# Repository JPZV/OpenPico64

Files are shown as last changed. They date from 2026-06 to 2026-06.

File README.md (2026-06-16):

# OpenPico64
Nintendo 64 flash cart using a Raspberry Pi Pico / RP2040 based on [kbeckmann](https://twitter.com/kbeckmann) [PicoCart64](https://github.com/kbeckmann/PicoCart64)

## How to build an OpenPico64

### Getting the raw PCB

- Download the `openpico64.gerber.zip` file from [Releases](https://github.com/JPZV/OpenPico64/releases/latest).

- Go to a PCB manufacturing service such as [JLCPCB](https://jlcpcb.com), [OSH Park](https://oshpark.com/), [PCBWay](https://pcbway.com) or similar.

- This takes you to the PCB configuration utility where you can upload the `.zip` from above. After uploading, you should see a rendered version of both sides of the PCB. If you want to produce a cheap cart for testing you can leave all settings as they are, except for this one:

  - ⚠️ *PCB Thickness* needs to be set to *1.2mm*, otherwise the cart won't fit in your console

⚠️ Note that this will result in a PCB with 90 degrees edges - the edge connector should be sanded down to get a nice 45 degree V shape. If this is not done, it may wear down your cart connector on the N64. The proper PCB order should be ENIG-RoHS + Gold Fingers + 45°finger chamfered, however this will result in a significant cost increase.

### Sourcing the components

In order to ensambe it you will need the following parts along with the PCBs. Here we're assuming you want to assemble 5 boards, as that is the number of PCBs you'll be getting from many PCB manufacturing services as a minimum.

⚠️ Note that this project **IS NOT** compatible with the original/oem `Raspberry Pi Pico`. **YOU HAVE** to use the [WeAct clone](https://aliexpress.com/item/1005003708090298.html) because it has more exposed pins which we need. I repeat, **DON'T** use the Raspberry Branded board (the green one with a Raspberry at the bottom), it will likely fry your N64 at best. I do recommend you to buy the 8MB version or higher, as I don't know how much will grow this project.

| Qty | Name | Source | 
|-----|---|---|
| 5 | WeAct Raspberry Pi Pico | [AliExpress](https://aliexpress.com/item/1005003708090298.html) | |
| 5 | BSS84 MOSFET | [750-BSS84-HF](https://www.mouser.com/ProductDetail/750-BSS84-HF) | |
| 5 | 0603 100k resistor | [71-CRCW0603100KJNEAC](https://www.mouser.com/ProductDetail/71-CRCW0603100KJNEAC) | |
| 5 | ATTINY85-20PU | [556-ATTINY85-20PU](https://www.mouser.com/ProductDetail/556-ATTINY85-20PU) | |

### Preparing the CIC (ATTiny85)

You have to flash the ATTiny85 with [UltraCIC](https://github.com/ManCloud/UltraCIC-III) before assembling everything else. You can do it with the OpenPico64 board headers to an easy installation. Then, **remember** to join the JP2 jumper!  

### Assembling the board

If your WeAct Pico didn't come with the headers ready, you'll have to solder them beforehand. Then, put the Pico on the OpenPico64 board with the USB connector facing outwards and solder the headers.

Solder the MOSFET according to the pin markings.

The resistor is optional to solder, but was placed there for good measure. (There is a resistor on the Pico, so it is not strictly needed.)

### Flashing/Updating the firmware

Go to the [Releases](https://github.com/JPZV/OpenPico64/releases/latest) and download the latest .UF2 file. **Remove the OpenPico64 from your N64**, then press and hold the **BOOTSEL** button while connecting the Pico to your computer. Open your file explorer (Explorer on Windows, Fiddle on Mac, and file manager in Linux), navigate to the new Flash memory, copy and paste the .UF2, and wait until it closes.

⚠️ **DON'T** use your OpenPico64 in your N64 while it's connected to your PC or anything. The N64 works with 3.3V and your computer with 5V, so likely it'll fry your N64.

## License

The PCB is licensed under the following license: "CERN Open Hardware Licence Version 2 - Permissive" aka "CERN-OHL-P".

The software is licensed under BSD-2-Clause unless otherwise specified.

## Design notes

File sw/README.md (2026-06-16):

To build and flash with a j-link:

```bash

# First of all, don't forget to update submodules
git submodule update --init

# If you have more than 2MB flash, you need to change the SDK file src/rp2_common/pico_standard_link/memmap_copy_to_ram.ld (for now!):
# Change to: `FLASH(rx) : ORIGIN = 0x10000000, LENGTH = 16384k`

cd sw

# Load a rom into sw/picocart64/rom.h
# `--compress` will compress the rom with a simple compression scheme.
./scripts/load_rom.py --compress my_rom.z64

mkdir build
cd build

# Configure cmake. To use NTSC, set -DREGION=NTSC
# If you have more than 2MB flash, you need to change the flash size by adding -DFLASH_SIZE_MB={one of 2,4,8,16} here.

cmake -DREGION=PAL ..

# Build
cmake --build .

# You can now flash it by holding down the BOOT button and resetting the device, then mounting the usb mass storage device, then copy the file openpico64/openpico64.uf2 to the mounted path and run `sync`.

# Alternatively, you can use openocd with a J-Link:

# Requires https://github.com/raspberrypi/openocd
# AUR package if you're on archlinux: https://aur.archlinux.org/packages/openocd-raspberrypi-git
openocd -f interface/jlink.cfg -c "transport select swd; adapter_khz 1000" -f target/rp2040.cfg -c "program ./openpico64/openpico64.elf verify reset exit"

# Note! You *have* to power reset the pico after flashing it with a jlink, otherwise multicore doesn't work properly.
# Alternatively, attach a debugger, `mon reset halt`, `c`, does the trick as well. It seems that openocd's `reset run` doesn't work properly.

```

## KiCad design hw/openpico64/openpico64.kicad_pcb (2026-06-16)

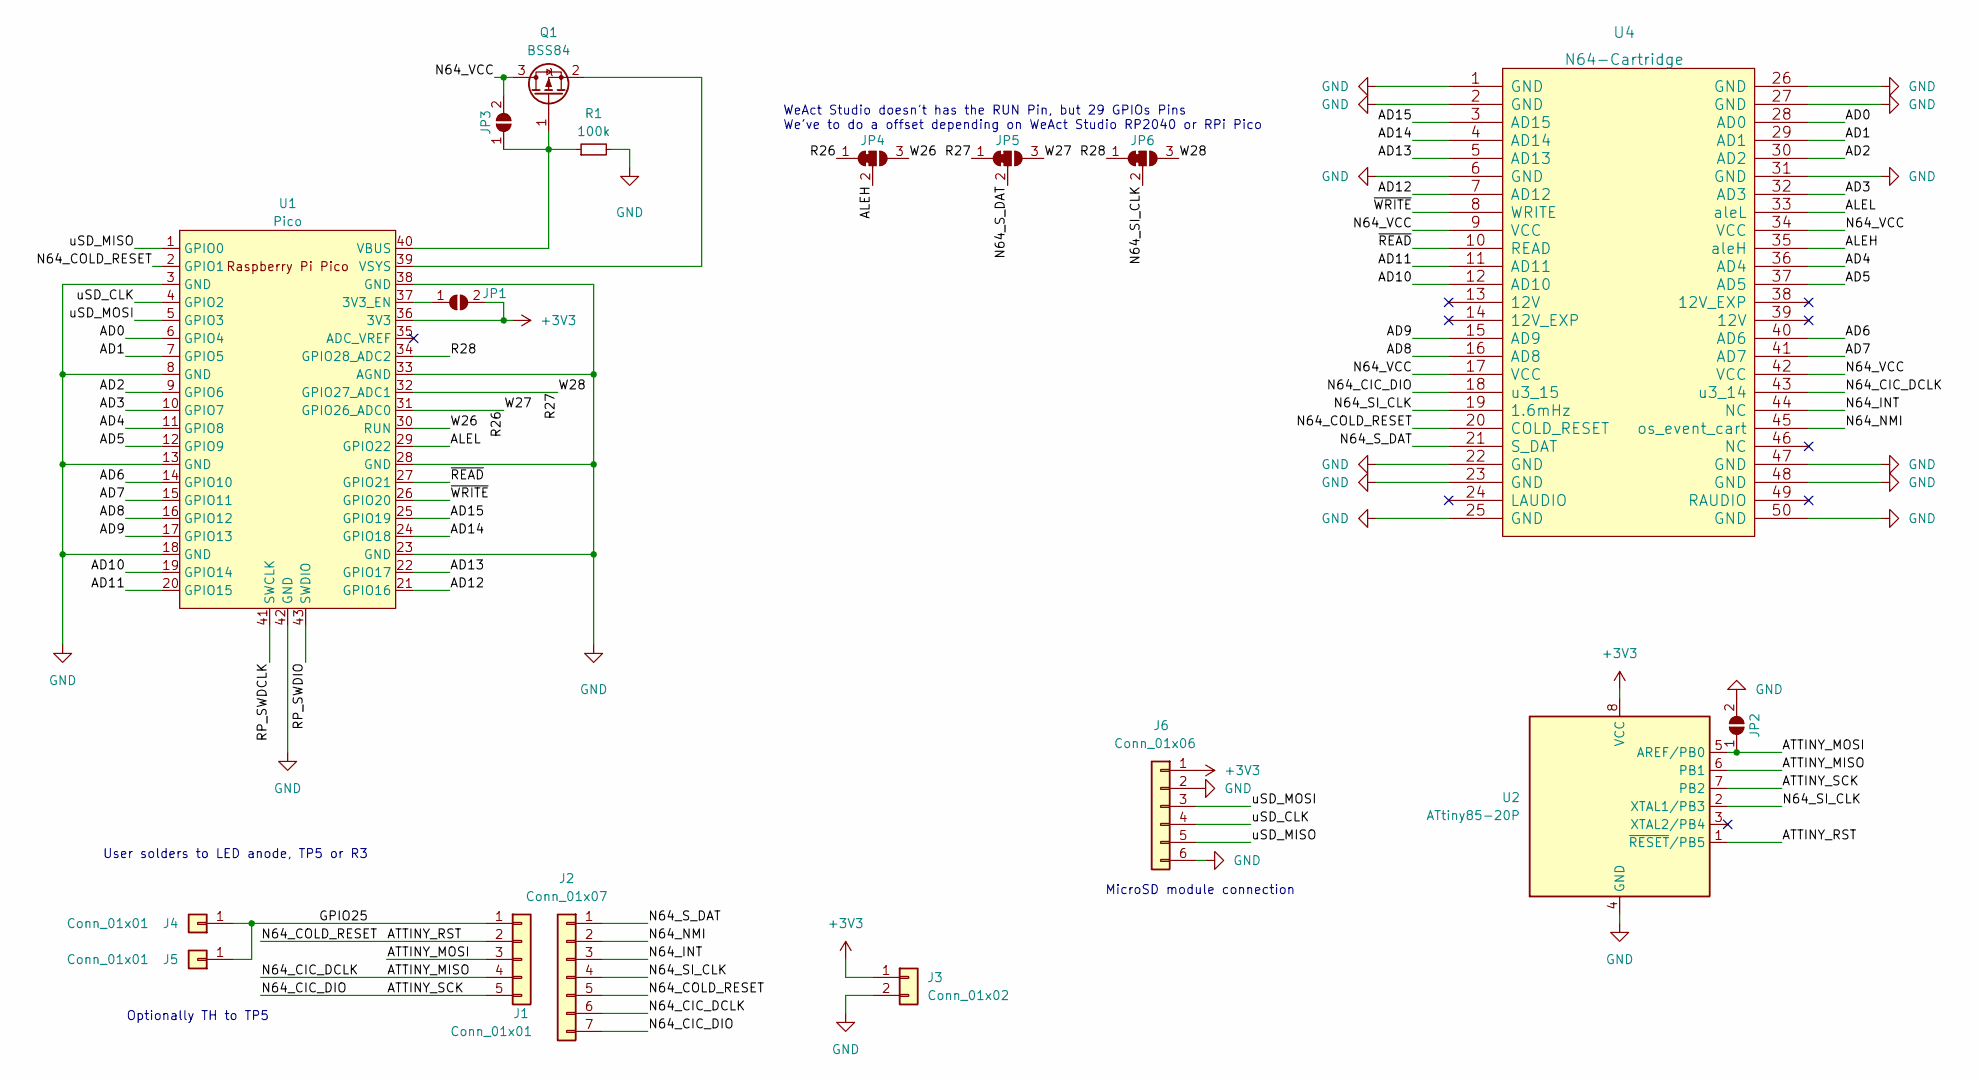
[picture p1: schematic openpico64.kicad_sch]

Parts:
J1: Conn_01x01; PinHeader_1x05_P2.54mm_Vertical
J2: Conn_01x07; PinHeader_1x07_P2.54mm_Vertical
J3: Conn_01x02; PinHeader_1x08_P2.54mm_Vertical
J4, J5: Conn_01x01; PinHeader_1x01_P2.54mm_Vertical
J6: Conn_01x06; PinHeader_1x06_P2.54mm_Vertical
JP1, JP2, JP3: SolderJumper_2_Open; SolderJumper-2_P1.3mm_Open_RoundedPad1.0x1.5mm
JP4, JP5, JP6: SolderJumper_3_Bridged12; SolderJumper-3_P1.3mm_Bridged12_RoundedPad1.0x1.5mm_NumberL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
Q1: BSS84; SOT-23
R1: 100k; R_0603_1608Metric_Pad0.98x0.95mm_HandSolder
U1: Pico; RPi_Pico_SMD_TH
U2: ATtiny85-20P; DIP-8_W7.62mm
U4: N64-Cartridge; N64-Connector

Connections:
+3V3: J3.1, J6.1, JP1.2 (B), U1.36 (3V3), U2.8 (VCC)
/AD0: U1.6 (GPIO4), U4.28 (AD0)
/AD1: U1.7 (GPIO5), U4.29 (AD1)
/AD2: U1.9 (GPIO6), U4.30 (AD2)
/AD3: U1.10 (GPIO7), U4.32 (AD3)
/AD4: U1.11 (GPIO8), U4.36 (AD4)
/AD5: U1.12 (GPIO9), U4.37 (AD5)
/AD6: U1.14 (GPIO10), U4.40 (AD6)
/AD7: U1.15 (GPIO11), U4.41 (AD7)
/AD8: U1.16 (GPIO12), U4.16 (AD8)
/AD9: U1.17 (GPIO13), U4.15 (AD9)
/AD10: U1.19 (GPIO14), U4.12 (AD10)
/AD11: U1.20 (GPIO15), U4.11 (AD11)
/AD12: U1.21 (GPIO16), U4.7 (AD12)
/AD13: U1.22 (GPIO17), U4.5 (AD13)
/AD14: U1.24 (GPIO18), U4.4 (AD14)
/AD15: U1.25 (GPIO19), U4.3 (AD15)
/ALEH: JP4.2 (C), U4.35 (aleH)
/ALEL: U1.29 (GPIO22), U4.33 (aleL)
/ATTINY_MISO: J1.4, J2.6, U2.6 (PB1), U4.43 (u3_14)
/ATTINY_MOSI: J1.3, JP2.1 (A), U2.5 (AREF/PB0)
/ATTINY_RST: J1.2, J2.5, U1.2 (GPIO1), U2.1 (~RESET/PB5), U4.20 (COLD_RESET)
/ATTINY_SCK: J1.5, J2.7, U2.7 (PB2), U4.18 (u3_15)
/GPIO25: J1.1, J4.1, J5.1
/N64_INT: J2.3, U4.44 (NC)
/N64_NMI: J2.2, U4.45 (os_event_cart)
/N64_SI_CLK: J2.4, JP6.2 (C), U2.2 (XTAL1/PB3), U4.19 (1.6mHz)
/N64_S_DAT: J2.1, JP5.2 (C), U4.21 (S_DAT)
/N64_VCC: JP3.2 (B), Q1.3 (D), U4.9 (VCC), U4.17 (VCC), U4.34 (VCC), U4.42 (VCC)
/R26: JP4.1 (A), JP5.3 (B), U1.31 (GPIO26_ADC0)
/R27: JP5.1 (A), JP6.3 (B), U1.32 (GPIO27_ADC1)
/R28: JP6.1 (A), U1.34 (GPIO28_ADC2)
/RP_SWDCLK: U1.41 (SWCLK)
/RP_SWDIO: U1.43 (SWDIO)
/W26: JP4.3 (B), U1.30 (RUN)
/uSD_CLK: J6.4, U1.4 (GPIO2)
/uSD_MISO: J6.5, U1.1 (GPIO0)
/uSD_MOSI: J6.3, U1.5 (GPIO3)
/~READ: U1.27 (GPIO21), U4.10 (READ)
/~WRITE: U1.26 (GPIO20), U4.8 (WRITE)
GND: J3.2, J6.2, J6.6, JP2.2 (B), R1.2, U1.3 (GND), U1.8 (GND), U1.13 (GND), U1.18 (GND), U1.23 (GND), U1.28 (GND), U1.33 (AGND), U1.38 (GND), U1.42 (GND), U2.4 (GND), U4.1 (GND), U4.2 (GND), U4.6 (GND), U4.22 (GND), U4.23 (GND), U4.25 (GND), U4.26 (GND), U4.27 (GND), U4.31 (GND), U4.47 (GND), U4.48 (GND), U4.50 (GND)
unnamed: JP1.1 (A), U1.37 (3V3_EN)
unnamed: JP3.1 (A), Q1.1 (G), R1.1, U1.40 (VBUS)
unnamed: Q1.2 (S), U1.39 (VSYS)

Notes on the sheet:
WeAct Studio doesn't has the RUN Pin, but 29 GPIOs Pins We've to do a offset depending on WeAct Studio RP2040 or RPi Pico
User solders to LED anode, TP5 or R3
Optionally TH to TP5
MicroSD module connection

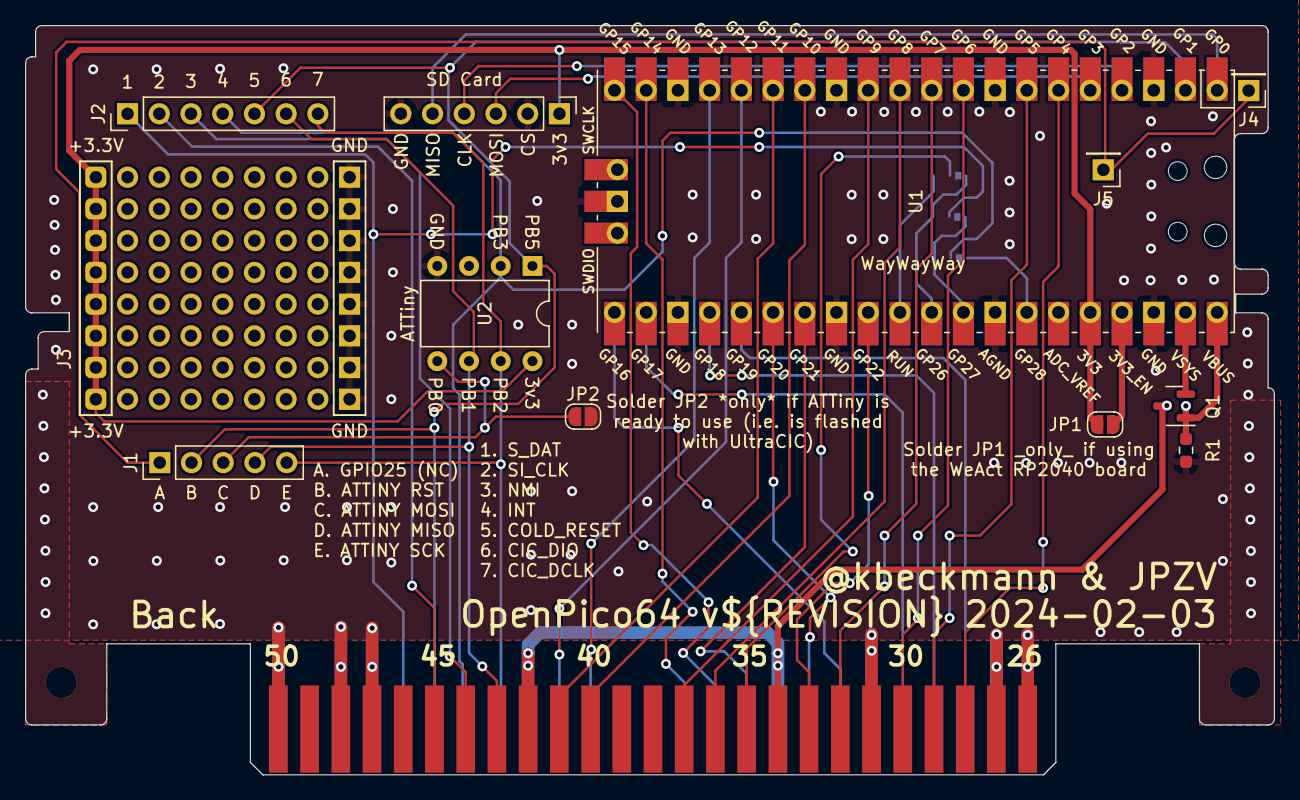
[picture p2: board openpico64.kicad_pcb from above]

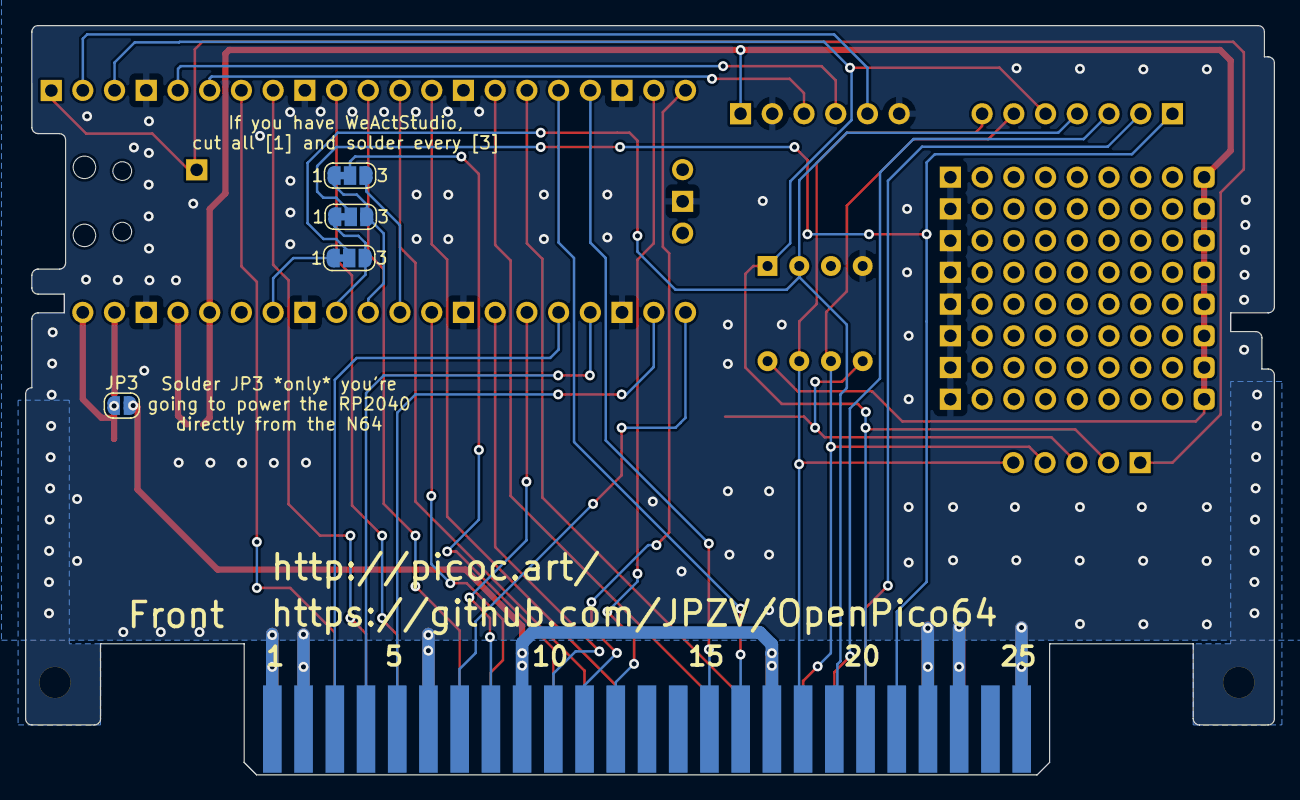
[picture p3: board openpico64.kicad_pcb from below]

Board: 2 copper layers, 100.0 x 60.0 mm, 17 parts (5 on the bottom side), 42 nets.

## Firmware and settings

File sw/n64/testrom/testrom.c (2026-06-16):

/**
 * SPDX-License-Identifier: BSD-2-Clause
 *
 * Copyright (c) 2022 Konrad Beckmann <konrad.beckmann@gmail.com>
 * Copyright (c) 2022 Christopher Bonhage <me@christopherbonhage.com>
 * Copyright (c) 2026 JPZV
 *
 * Based on https://github.com/meeq/SaveTest-N64
 */

#include <string.h>
#include <libdragon.h>

#include "git_info.h"
#include "shell.h"
#include "testrom.h"

// picocart64_shared
#include "pc64_regs.h"
#include "pc64_rand.h"
#include "n64_defs.h"

typedef struct PI_regs_s {
	volatile void *ram_address;
	uint32_t pi_address;
	uint32_t read_length;
	uint32_t write_length;
} PI_regs_t;
static volatile PI_regs_t *const PI_regs = (PI_regs_t *) 0xA4600000;

// SD Card Test constants
#define SD_TEST_PATH				"/New Path/My Folder/"

static void verify_memory_range(uint32_t base, uint32_t offset, uint32_t len)
{
	uint32_t start = base + offset;
	uint32_t end = start + len - 1;

	switch (base) {
	case CART_DOM2_ADDR1_START:
		assert(start >= CART_DOM2_ADDR1_START);
		assert(start <= CART_DOM2_ADDR1_END);
		assert(end >= CART_DOM2_ADDR1_START);
		assert(end <= CART_DOM2_ADDR1_END);
		break;

	case CART_DOM1_ADDR1_START:
		assert(start >= CART_DOM1_ADDR1_START);
		assert(start <= CART_DOM1_ADDR1_END);
		assert(end >= CART_DOM1_ADDR1_START);
		assert(end <= CART_DOM1_ADDR1_END);
		break;

	case CART_DOM2_ADDR2_START:
		assert(start >= CART_DOM2_ADDR2_START);
		assert(start <= CART_DOM2_ADDR2_END);
		assert(end >= CART_DOM2_ADDR2_START);
		assert(end <= CART_DOM2_ADDR2_END);
		break;

	case CART_DOM1_ADDR2_START:
		assert(start >= CART_DOM1_ADDR2_START);
		assert(start <= CART_DOM1_ADDR2_END);
		assert(end >= CART_DOM1_ADDR2_START);
		assert(end <= CART_DOM1_ADDR2_END);
		break;

	case CART_DOM1_ADDR3_START:
		assert(start >= CART_DOM1_ADDR3_START);
		assert(start <= CART_DOM1_ADDR3_END);
		assert(end >= CART_DOM1_ADDR3_START);
		assert(end <= CART_DOM1_ADDR3_END);
		break;

	case PC64_BASE_ADDRESS_START:
		assert(start >= PC64_BASE_ADDRESS_START);
		assert(start <= PC64_BASE_ADDRESS_END);
		assert(end >= PC64_BASE_ADDRESS_START);
		assert(end <= PC64_BASE_ADDRESS_END);
		break;

	case PC64_RAND_ADDRESS_START:
		assert(start >= PC64_RAND_ADDRESS_START);
		assert(start <= PC64_RAND_ADDRESS_END);
		assert(end >= PC64_RAND_ADDRESS_START);
		assert(end <= PC64_RAND_ADDRESS_END);
		break;

	case PC64_CIBASE_ADDRESS_START:
		assert(start >= PC64_CIBASE_ADDRESS_START);
		assert(start <= PC64_CIBASE_ADDRESS_END);
		assert(end >= PC64_CIBASE_ADDRESS_START);
		assert(end <= PC64_CIBASE_ADDRESS_END);
		break;
	
	case SD_PATH_ADDR_START:
	case SD_GAME_PATH_ADDR_START:
	case SD_STATUS_ADDR_START:
	case SD_DIR_LIST_LEN_ADDR_START:
	case SD_DIR_LIST_ADDR_START:
		assert(start >= SD_ADDR_START);
		assert(start <= SD_ADDR_END);
		assert(end >= SD_ADDR_START);
		assert(end <= SD_ADDR_END);
		break;

	default:
		assert(!"Unsupported base");
	}
}

void pi_read_raw(void *dest, uint32_t base, uint32_t offset, uint32_t len)
{
	assert(dest != NULL);
	verify_memory_range(base, offset, len);

	disable_interrupts();
	dma_wait();

	MEMORY_BARRIER();
	PI_regs->ram_address = UncachedAddr(dest);
	MEMORY_BARRIER();
	PI_regs->pi_address = offset + base;
	MEMORY_BARRIER();
	PI_regs->write_length = len - 1;
	MEMORY_BARRIER();

	enable_interrupts();
	dma_wait();
}

void pi_write_raw(const void *src, uint32_t base, uint32_t offset, uint32_t len)
{
	assert(src != NULL);
	verify_memory_range(base, offset, len);

	disable_interrupts();
	dma_wait();

	MEMORY_BARRIER();
	PI_regs->ram_address = UncachedAddr(src);
	MEMORY_BARRIER();
	PI_regs->pi_address = offset + base;
	MEMORY_BARRIER();
	PI_regs->read_length = len - 1;
	MEMORY_BARRIER();

	enable_interrupts();
	dma_wait();
}

static void pi_write_u32(const uint32_t value, uint32_t base, uint32_t offset)
{
	uint32_t buf[] = { value };

	data_cache_hit_writeback_invalidate(buf, sizeof(buf));
	pi_write_raw(buf, base, offset, sizeof(buf));
}

static uint8_t __attribute__((aligned(16))) facit_buf[SRAM_1MBIT_SIZE];
static uint8_t __attribute__((aligned(16))) read_buf[SRAM_1MBIT_SIZE];
static char __attribute__((aligned(16))) write_buf[0x1000];

char __attribute__((aligned(16))) path_read_buf[SD_PATH_LENGTH];

static void pc64_uart_write(const uint8_t * buf, uint32_t len)
{
	// 16-bit aligned
	assert((((uint32_t) buf) & 0x1) == 0);

	uint32_t len_aligned32 = (len + 3) & (-4);

	data_cache_hit_writeback_invalidate((uint8_t *) buf, len_aligned32);
	pi_write_raw(write_buf, PC64_BASE_ADDRESS_START, 0, len_aligned32);

	pi_write_u32(len, PC64_CIBASE_ADDRESS_START, PC64_REGISTER_UART_TX);
}

static void configure_sram(void)
{
	// PI registers
#define PI_BASE_REG          0x04600000
#define PI_STATUS_REG        (PI_BASE_REG+0x10)
#define	PI_STATUS_ERROR      0x04
#define PI_STATUS_IO_BUSY    0x02
#define PI_STATUS_DMA_BUSY   0x01

#define PI_BSD_DOM1_LAT_REG  (PI_BASE_REG+0x14)
#define PI_BSD_DOM1_PWD_REG  (PI_BASE_REG+0x18)
#define PI_BSD_DOM1_PGS_REG  (PI_BASE_REG+0x1C)
#define PI_BSD_DOM1_RLS_REG  (PI_BASE_REG+0x20)
#define PI_BSD_DOM2_LAT_REG  (PI_BASE_REG+0x24)
#define PI_BSD_DOM2_PWD_REG  (PI_BASE_REG+0x28)
#define PI_BSD_DOM2_PGS_REG  (PI_BASE_REG+0x2C)
#define PI_BSD_DOM2_RLS_REG  (PI_BASE_REG+0x30)

	// MIPS addresses
#define KSEG0 0x80000000
#define KSEG1 0xA0000000

	// Memory translation stuff
#define	PHYS_TO_K1(x)       ((uint32_t)(x)|KSEG1)
#define	IO_WRITE(addr,data) (*(volatile uint32_t *)PHYS_TO_K1(addr)=(uint32_t)(data))
#define	IO_READ(addr)       (*(volatile uint32_t *)PHYS_TO_K1(addr))

	// Initialize the PI
	IO_WRITE(PI_STATUS_REG, 3);

	// SDK default, 0x80371240
	//                  DCBBAA
	// AA = LAT
	// BB = PWD
	//  C = PGS
	//  D = RLS
	//
	// 1 cycle = 1/62.5 MHz = 16ns
	// Time = (register+1)*16ns
	// LAT = tL = 0x40 = 65 cycles
	// PWM = tP = 0x12 = 19 cycles
	// PGS      = 0x07 = 512 bytes page size
	// RLS = tR = 0x03 = 4 cycles

#if 0
	IO_WRITE(PI_BSD_DOM1_LAT_REG, 0x40);
	IO_WRITE(PI_BSD_DOM1_PWD_REG, 0x12);
	IO_WRITE(PI_BSD_DOM1_PGS_REG, 0x07);
	IO_WRITE(PI_BSD_DOM1_RLS_REG, 0x03);

	IO_WRITE(PI_BSD_DOM2_LAT_REG, 0x40);
	IO_WRITE(PI_BSD_DOM2_PWD_REG, 0x12);
	IO_WRITE(PI_BSD_DOM2_PGS_REG, 0x07);
	IO_WRITE(PI_BSD_DOM2_RLS_REG, 0x03);

#else

	// Fast SRAM access (matches default values from SDK)
	IO_WRITE(PI_BSD_DOM2_LAT_REG, 0x40);
	IO_WRITE(PI_BSD_DOM2_PWD_REG, 0x0C);
	IO_WRITE(PI_BSD_DOM2_PGS_REG, 0x07);
	IO_WRITE(PI_BSD_DOM2_RLS_REG, 0x03);

	// LAT: 0x04 works when banked mode is disabled
#endif
}

int main(void)
{
	uint32_t *facit_buf32 = (uint32_t *) facit_buf;
	uint32_t *read_buf32 = (uint32_t *) read_buf;
	uint16_t *read_buf16 = (uint16_t *) read_buf;
	int fail_count = 0;

	configure_sram();

	display_init(RESOLUTION_320x240, DEPTH_32_BPP, 2, GAMMA_NONE, ANTIALIAS_RESAMPLE);
	console_init();
	// debug_init_isviewer();

	printf("PicoCart64 Test ROM (git rev %08X)\n\n", GIT_REV);

	///////////////////////////////////////////////////////////////////////////

	// Verify PicoCart64 Magic
	data_cache_hit_writeback_invalidate(read_buf, sizeof(read_buf));
	pi_read_raw(read_buf, PC64_CIBASE_ADDRESS_START, PC64_REGISTER_MAGIC, sizeof(uint32_t));
	if (read_buf32[0] == PC64_MAGIC) {
		printf("[ OK ] MAGIC = 0x%08lX.\n", read_buf32[0]);
	} else {
		fail_count++;
		printf("[FAIL] MAGIC = 0x%08lX.\n", read_buf32[0]);
	}

	///////////////////////////////////////////////////////////////////////////

	// Read the Flash JEDEC ID
	data_cache_hit_writeback_invalidate(read_buf, sizeof(read_buf));
	pi_read_raw(read_buf, PC64_CIBASE_ADDRESS_START, PC64_REGISTER_FLASH_JEDEC_ID, sizeof(uint32_t));
	printf("[ -- ] Flash JEDEC ID = 0x%08lX.\n", read_buf32[0]);

	if (read_buf32[0] != 0x001540ef) {
		printf("[ ?? ] Non-standard flash detected\n");
	}
	///////////////////////////////////////////////////////////////////////////

	// Print Hello from the N64
	strcpy(write_buf, "Hello from the N64!\r\n");
	pc64_uart_write((const uint8_t *)write_buf, strlen(write_buf));
	printf("[ -- ] Wrote hello over UART.\n");

	///////////////////////////////////////////////////////////////////////////

	// Initialize a random sequence
	pc64_rand_seed(0);
	data_cache_hit_writeback_invalidate(facit_buf, sizeof(facit_buf));
	for (int i = 0; i < sizeof(facit_buf) / sizeof(uint32_t); i++) {
		facit_buf32[i] = pc64_rand32();
	}

	// Read back 1Mbit of SRAM
	data_cache_hit_writeback_invalidate(read_buf, sizeof(read_buf));
	pi_read_raw(read_buf, CART_DOM2_ADDR2_START, 0, sizeof(read_buf));

	// Compare SRAM with the facit
	if (memcmp(facit_buf, read_buf, sizeof(read_buf)) != 0) {
		printf("[////] SRAM was not backed up properly.\n");
		printf("[ !! ] Should pass if you press the N64 reset button.\n");

		for (int i = 0; i < sizeof(facit_buf) / sizeof(uint32_t); i++) {
			if (facit_buf32[i] != read_buf32[i]) {
				printf("       Error @%d: facit %08lX != sram %08lX\n", i, facit_buf32[i], read_buf32[i]);
				break;
			}
		}
	} else {
		printf("[ OK ] SRAM was backed up properly.\n");
	}

	///////////////////////////////////////////////////////////////////////////

	// Write 1Mbit of SRAM
	data_cache_hit_writeback_invalidate(facit_buf, sizeof(facit_buf));
	pi_write_raw(facit_buf, CART_DOM2_ADDR2_START, 0, sizeof(facit_buf));

	printf("[ -- ] Wrote test pattern to SRAM.\n");

	// Read it back and verify
	data_cache_hit_writeback_invalidate(read_buf, sizeof(read_buf));
	pi_read_raw(read_buf, CART_DOM2_ADDR2_START, 0, sizeof(read_buf));

	// Compare SRAM with the facit
	if (memcmp(facit_buf, read_buf, sizeof(read_buf)) != 0) {
		fail_count++;
		printf("[FAIL] Volatile SRAM did not verify correctly.\n");

		for (int i = 0; i < sizeof(facit_buf) / sizeof(uint32_t); i++) {
			if (facit_buf32[i] != read_buf32[i]) {
				printf("       Error @%d: facit %08lX != sram %08lX\n", i, facit_buf32[i], read_buf32[i]);
				break;
			}
		}
	} else {
		printf("[ OK ] Volatile SRAM verified correctly.\n");
	}

	///////////////////////////////////////////////////////////////////////////

	// Read Current FS Path
	data_cache_hit_writeback_invalidate(path_read_buf, sizeof(path_read_buf));
	pi_read_raw(path_read_buf, SD_PATH_ADDR_START, 0, sizeof(path_read_buf));
	printf("[ -- ] Current Dir = '%s'.\n", path_read_buf);
	
	printf("[ -- ] Setting current Dir to '%s' (%d chars).\n", SD_TEST_PATH, strlen(SD_TEST_PATH));
	change_dir(SD_TEST_PATH);

	data_cache_hit_writeback_invalidate(path_read_buf, sizeof(path_read_buf));
	pi_read_raw(path_read_buf, SD_PATH_ADDR_START, 0, sizeof(path_read_buf));
	printf("[ -- ] Current Dir = '%s'.\n", path_read_buf);
	if (strcmp(SD_TEST_PATH, path_read_buf) != 0) {
		fail_count++;
		printf("[FAIL] Current Dir wasn't changed correctly!.\n");

		printf("       Error: Test '%s' != CWD '%s'.\n", SD_TEST_PATH, path_read_buf);
	} else {
		printf("[ OK ] Currect Dir was changed correctly!.\n");
	}

	///////////////////////////////////////////////////////////////////////////

	// Stress test: Read pseudo-random numbers from PicoCart64 RAND address space
	// Reset random seed
	pi_write_u32(0, PC64_CIBASE_ADDRESS_START, PC64_REGISTER_RAND_SEED);
	pc64_rand_seed(0);

	// Compare buffer with RNG
	printf("[ -- ] PicoCart64 RNG stress-test: ");
	bool rng_ok = true;
	for (int j = 0; j < 64 && rng_ok; j++) {
		// Read back 1Mbit of RAND values
		data_cache_hit_writeback_invalidate(read_buf, sizeof(read_buf));
		pi_read_raw(read_buf, PC64_RAND_ADDRESS_START, 0, sizeof(read_buf));
		printf(".");
		fflush(stdout);

		for (int i = 0; i < sizeof(read_buf) / sizeof(uint16_t); i++) {
			uint16_t value = pc64_rand16();

			if (value != read_buf16[i]) {
				printf("\n       Error @%d: ours %04X != theirs %04X", i, value, read_buf16[i]);
				rng_ok = false;
				break;
			}
		}
	}

	if (rng_ok) {
		printf("\n[ OK ] Random stress test verified correctly.\n");
	} else {
		fail_count++;
		printf("\n[FAIL] Random stress test failed.\n");
	}

	///////////////////////////////////////////////////////////////////////////

	// Read 1Mbit of 64DD IPL ROM
	data_cache_hit_writeback_invalidate(read_buf, sizeof(read_buf));
	pi_read_raw(read_buf, CART_DOM1_ADDR1_START, 0, sizeof(read_buf));
	printf("[ -- ] Read from the N64DD address space.\n");

	// Verify the PicoCart64 Magic *again*
	// This is done to ensure that the PicoCart64 is still alive and well,
	// and hasn't crashed or locked itself up.
	data_cache_hit_writeback_invalidate(read_buf, sizeof(read_buf));
	pi_read_raw(read_buf, PC64_CIBASE_ADDRESS_START, PC64_REGISTER_MAGIC, sizeof(uint32_t));
	if (read_buf32[0] == PC64_MAGIC) {
		printf("[ OK ] (second time) MAGIC = 0x%08lX.\n", read_buf32[0]);
	} else {
		fail_count++;
		printf("[FAIL] (second time) MAGIC = 0x%08lX.\n", read_buf32[0]);
		printf("       PicoCart64 might stall now and require a power cycle.\n");
	}

	if (fail_count == 0)
	{
		printf("\n[ OK ] Test is finished. All tests passed.\n");
	}
	else
	{
		printf("\n[FAIL] Test is finished. %d tests failed.\n", fail_count);
	}
	printf("\n");

	console_render();

	if (fail_count > 0)
	{
		/* Start the shell if the user presses start */
		printf("\n\nPress START to continue to the shell...\n");
		controller_init();
		while (1)
		{	
			controller_scan();
			struct controller_data keys = get_keys_pressed();
			if (keys.c[0].start)
			{
				printf("Start pressed.\n");
				break;
			}
		}
	}

	start_shell();
}

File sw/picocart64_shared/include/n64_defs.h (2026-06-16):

/**
 * SPDX-License-Identifier: BSD-2-Clause
 *
 * Copyright (c) 2022 Konrad Beckmann
 * Copyright (c) 2026 JPZV
 */

#pragma once

// N64DD control registers
#define CART_DOM2_ADDR1_START       0x05000000
#define CART_DOM2_ADDR1_END         0x05FFFFFF

// N64DD IPL ROM
#define CART_DOM1_ADDR1_START       0x06000000
#define CART_DOM1_ADDR1_END         0x07FFFFFF

// Cartridge SRAM
#define CART_DOM2_ADDR2_START       0x08000000
#define CART_DOM2_ADDR2_END         0x0FFFFFFF

// Define the highest supported banked SRAM addresses
#define CART_SRAM_START             CART_DOM2_ADDR2_START
#define CART_SRAM_END               (CART_DOM2_ADDR2_START + 0x100000 - 1)

// Cartridge ROM
#define CART_DOM1_ADDR2_START       0x10000000
#define CART_DOM1_ADDR2_END         0x1FBFFFFF


// SD Content
#define SD_ADDR_START               0x1FD00000

#define SD_PATH_ADDR_START          SD_ADDR_START
#define SD_PATH_LENGTH              256
#define SD_PATH_ADDR_END            (SD_PATH_ADDR_START + SD_PATH_LENGTH + 1)

#define SD_GAME_PATH_ADDR_START     0x1FD01000
#define SD_GAME_PATH_LENGTH         256
#define SD_GAME_PATH_ADDR_END       (SD_GAME_PATH_ADDR_START + SD_GAME_PATH_LENGTH + 1)

#define SD_STATUS_ADDR_START        0x1FD02000
#define SD_STATUS_ADDR_END          (SD_STATUS_ADDR_START + 2)

#define SD_DIR_LIST_LEN_ADDR_START  0x1FD03000
#define SD_DIR_LIST_LEN_ADDR_END    (SD_DIR_LIST_LEN_ADDR_START + 2)

#define SD_DIR_LIST_ADDR_START      0x1FD04000
#define SD_DIR_LIST_LENGTH          0x20000
#define SD_DIR_LIST_ADDR_END        (SD_DIR_LIST_ADDR_START + SD_DIR_LIST_LENGTH)

#define SD_ADDR_END                 (SD_DIR_LIST_LEN_ADDR_END + 0x100000)


// Unknown
#define CART_DOM1_ADDR3_START       SD_ADDR_END
#define CART_DOM1_ADDR3_END         0x7FFFFFFF


typedef enum
{
    FS_OK,
    FS_STARTING,
    FS_SD_SELECTED,
    FS_LOADING_CONTENT,
    FS_INIT_DRIVER,
    FS_MOUNTING,
    FS_LOADING_FIRST_ITEM,
    FS_CLEANING_CONTENT_ARRAY,
    FS_COUNTING_CONTENT,
    FS_CREATING_CONTENT_ARRAY,
    // Every error MUST be below this line
    FS_TASK_ENTRY, // Funny thing: This line SHOULD only be called once at the very beginning of the code.
                   // So, it's an error if we get that status
    FS_FAILED_MOUNTING,
    FS_FAILED_LOADING_FIRST_ITEM_COUNT,
    FS_FAILED_LOADING_FIRST_ITEM_LIST,
    FS_UNKNOWN
} FS_STATUS;

typedef enum
{
    FS_GAME_OK,
    FS_GAME_STARTING,
    FS_GAME_OPENING,
    FS_GAME_WAITING_RESET,
    // Every error MUST be below this line
    FS_GAME_OPEN_FAILED,
    FS_GAME_UNKNOWN
} FS_GAME_STATUS;

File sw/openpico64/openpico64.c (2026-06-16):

/**
 * SPDX-License-Identifier: BSD-2-Clause
 *
 * Copyright (c) 2022 Konrad Beckmann
 * Copyright (c) 2026 JPZV
 */

#include <stdio.h>
#include <string.h>

#include "FreeRTOS.h"
#include "task.h"

#include "pico/stdlib.h"
#include "pico/multicore.h"
#include "hardware/flash.h"
#include "hardware/irq.h"

#include "stdio_async_uart.h"

#include "git_info.h"
#include "filesystem.h"
#include "n64_pi_task.h"
#include "openpico64_pins.h"
#include "sram.h"
#include "utils.h"

#define UART_TX_PIN (25) /* On-Board LED */ // NOTE: Will not work becase PIO is between 4 and 26
#define UART_RX_PIN (23) /* not available on the pico */
#define UART_ID     uart0
#define BAUD_RATE   115200

#define ENABLE_N64_PI 1

// Priority 0 = lowest, 3 = highest
#define SRAM_TASK_PRIORITY     (3UL)

static StaticTask_t sram_task;
static StackType_t sram_task_stack[4 * 1024 / sizeof(StackType_t)];

uint32_t g_flash_jedec_id;

/*

Profiling results:

Time between ~N64_READ and bit output on AD0

133 MHz old code:
    ROM:  1st _980_ ns, 2nd 500 ns
    SRAM: 1st  500  ns, 2nd 510 ns

133 MHz new code:
    ROM:  1st _300_ ns, 2nd 280 ns
    SRAM: 1st  320  ns, 2nd 320 ns

266 MHz new code:
    ROM:  1st  180 ns, 2nd 180 ns (sometimes down to 160, but only worst case matters)
    SRAM: 1st  160 ns, 2nd 160 ns

*/

// FreeRTOS boilerplate
void vApplicationGetTimerTaskMemory(StaticTask_t ** ppxTimerTaskTCBBuffer, StackType_t ** ppxTimerTaskStackBuffer, uint32_t * pulTimerTaskStackSize)
{
	static StaticTask_t xTimerTaskTCB;
	static StackType_t uxTimerTaskStack[configTIMER_TASK_STACK_DEPTH];

	*ppxTimerTaskTCBBuffer = &xTimerTaskTCB;
	*ppxTimerTaskStackBuffer = uxTimerTaskStack;
	*pulTimerTaskStackSize = configTIMER_TASK_STACK_DEPTH;
}

void sram_task_entry(__unused void *params)
{
	printf("sram_task_entry\n");

	// Load SRAM backup from external flash
	// TODO: How do we detect if it's uninitialized (config area in flash?),
	//       or maybe we don't have to care?
	sram_load_from_flash();

	// Save SRAM backup to external flash
	// We do it by checking the times it's used (either by READ or WRITE)

	// We start the last counter by 255 in order to force a save to flash at the start
	uint8_t last_sram_counter = sram_counter;
	while (true)
	{
		if (last_sram_counter != sram_counter)
		{
			sram_save_to_flash();
			last_sram_counter = sram_counter;
		}
		vTaskDelay(100 / portTICK_PERIOD_MS);
	}
	
	vTaskDelete(NULL);
}

void vLaunch(void)
{
	xTaskCreateStatic(sram_task_entry, "sram_task", configMINIMAL_STACK_SIZE, NULL, SRAM_TASK_PRIORITY, sram_task_stack, &sram_task);

	/* Start the tasks and timer running. */
	vTaskStartScheduler();
}

#include "rom_vars.h"

uint32_t flash_get_jedec_id(void)
{
	const uint8_t read_jedec_id = 0x9f;
	uint8_t txbuf[4] = { read_jedec_id };
	uint8_t rxbuf[4] = { 0 };
	txbuf[0] = read_jedec_id;
	flash_do_cmd(txbuf, rxbuf, 4);

	return rxbuf[1] | (rxbuf[2] << 8) | (rxbuf[3] << 16);
}

int main(void)
{
	// First, let's probe the Flash ID
	g_flash_jedec_id = flash_get_jedec_id();

	// Overclock!
	// The external flash should be rated to 133MHz,
	// but since it's used with a 2x clock divider,
	// 266 MHz is safe in this regard.

	// set_sys_clock_khz(133000, true);
	set_sys_clock_khz(266000, true);	// Required for SRAM @ 200ns

	// Init GPIOs before starting the second core and FreeRTOS
	for (int i = 0; i <= 27; i++) {
		gpio_init(i);
		switch (i)
		{
			default:
				gpio_set_dir(i, GPIO_IN);
				gpio_set_pulls(i, false, false);
				break;
			case SD_MISO:
			case SD_CLK:
			case SD_MOSI:
				gpio_set_function(i, GPIO_FUNC_SPI);
				if (i == SD_MISO) 
				{
					gpio_set_pulls(i, true, false);
				}
				break;
		}
	}

	// Set up ROM mapping table
	if (memcmp(picocart_header, "picocartcompress", 16) == 0) {
		// Copy rom compressed map from flash into RAM
		memcpy(rom_mapping, flash_rom_mapping, MAPPING_TABLE_LEN * sizeof(uint16_t));
	} else {
		for (int i = 0; i < MAPPING_TABLE_LEN; i++) {
			rom_mapping[i] = i;
		}
	}

	// Init UART on pin 25/23
	stdio_async_uart_init_full(UART_ID, BAUD_RATE, UART_TX_PIN, UART_RX_PIN);
	printf("PicoCart64 Boot (git rev %08x)\r\n", GIT_REV);

#if ENABLE_N64_PI
	// Launch the N64 PI implementation in the second core
	// Note! You have to power reset the pico after flashing it with a jlink,
	//       otherwise multicore doesn't work properly.
	//       Alternatively, attach gdb to openocd, run `mon reset halt`, `c`.
	//       It seems this works around the issue as well.
	multicore_launch_core1(n64_pi_run);
#endif

	// Start SD Card FileSystem
	fs_init();

	// Start FreeRTOS on Core0
	vLaunch();

	return 0;
}

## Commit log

2026-06-16 Renamed PicoCart64 to OpenPico64
    [picocart64_v1-B_Cu.gbl, picocart64_v1-B_Mask.gbs, picocart64_v1-B_Silkscreen.gbo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]
2026-06-16 Removed gerber files
    [picocart64_v1-B_Cu.gbl, picocart64_v1-B_Mask.gbs, picocart64_v1-B_Silkscreen.gbo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]
2026-06-16 Moved CIC to separated IC
    this helps us to allocate more pins
    [openpico64.kicad_pcb, openpico64.kicad_sch, picocart64_v1.kicad_pcb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]
